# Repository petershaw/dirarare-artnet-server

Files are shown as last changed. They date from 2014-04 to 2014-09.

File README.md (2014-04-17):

dirarare-artnet-server
======================

A ArtNet to DMX node

## Hardware ##
### Schematics ###

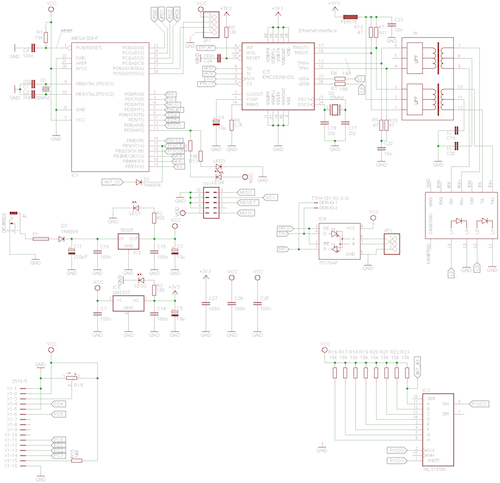
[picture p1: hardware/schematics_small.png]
Schematics


[Full sized schematics](./hardware/schematics.png).

### Partlist ###

| Part | Value |
|:---|---:|
| C1 | 22p |  
| C2 | 22p |
| C3 | 10µ |
| C4 | 100n |
| C5 | 10µ |
| C6 | 10µ |
| C7 | 100n |
| C11 | 220µF |
| C14 | 100n |
| C15 | 100n |
| C16 | 100n |
| C17 | 22p |
| C18 | 22p |
| C19 | 1n |
| C20 | 1n | 
| C22 | 10n | 
| C23 | 10n | 
| C24 | 100n | 
| C25 | 100n | 
| C26 | 100n | 
| C27 | 100n | 
| D1 | 1N4004 | 
| D3 | 1N4004 | 
| DEBUG | TSW-101-02-S-Q |
| F1 | | 
| FERITE | | 
| IC1 | MEGA328-P |
| IC2 | 78S05 |
| IC3 | 74LS165N |  
| IC4 | 75176AP |
| IC5 | ENC28J60-DIL | 
| IC6 | LM2937 |
| J1 | DCJ0202 |
| JP1 | |
| JP2 | |
| LED1 | |
| LED2 | |
| LED3 | |
| LED4 | | 
| Q1 | 20Mhz | 
| Q2 | 25Mhz | 
| R1 | 10k |
| R2 | 820 |
| R3 | 180 |
| R4 | 180 |
| R5 | 10k |
| R6 | 180 |
| R7 | 180 |
| R8 | 2,7k |
| R9 | 47 |
| R10 | 47 |
| R11 | 47 |
| R12 | 47 |
| R13 | 180 |
| R14 | |
| R15 | 180 | 
| R16 | 10k |
| R17 | 10k |
| R18 | 10k |
| R19 | 10k |
| R20 | 10k |
| R21 | 10k |
| R22 | 10k |
| R23 | 10k |
| SV1 | |
| TR | |
| U$1 | |
| X1 | 2516-5 | 

## Software ##

t.b.d. take a look in the code

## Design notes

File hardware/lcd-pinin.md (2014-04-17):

Pin #-LCD	Bezeichnung-LCD	Pin-µC
1	Vss	GND
2	Vcc	5V
3	Vee	GND oder Poti (siehe oben)
4	RS	PD4 am AVR
5	RW	GND
6	E	PD5 am AVR
7	DB0	offen (unbenutzt)
8	DB1	
9	DB2	
10	DB3	
11	DB4	PC0 am AVR
12	DB5	PC1 am AVR
13	DB6	PC2 am AVR
14	DB7	PC3 am AVR

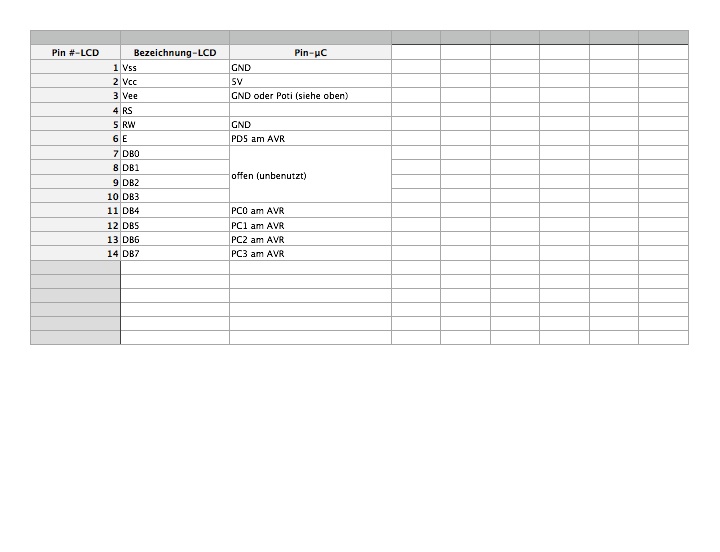
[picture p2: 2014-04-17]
hardware/Pinout-LCD.numbers/preview.jpg

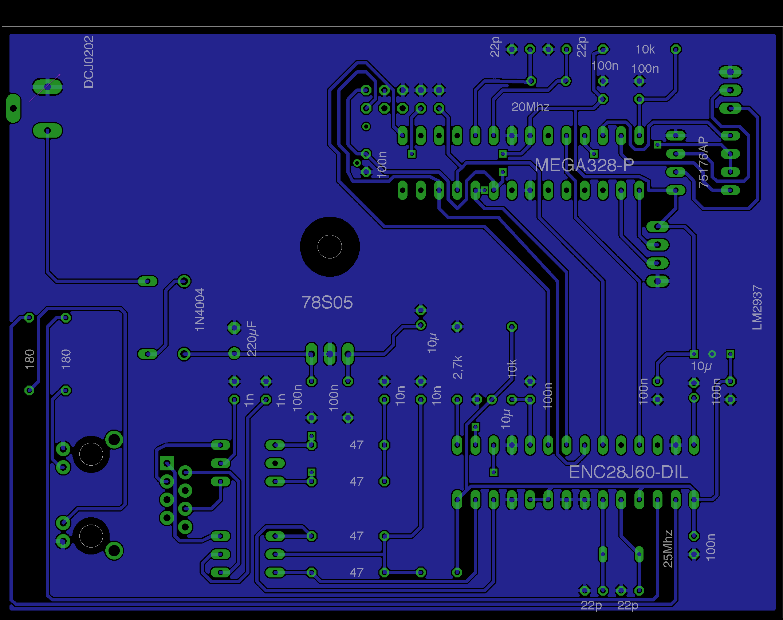
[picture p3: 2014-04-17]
hardware/gnd.png

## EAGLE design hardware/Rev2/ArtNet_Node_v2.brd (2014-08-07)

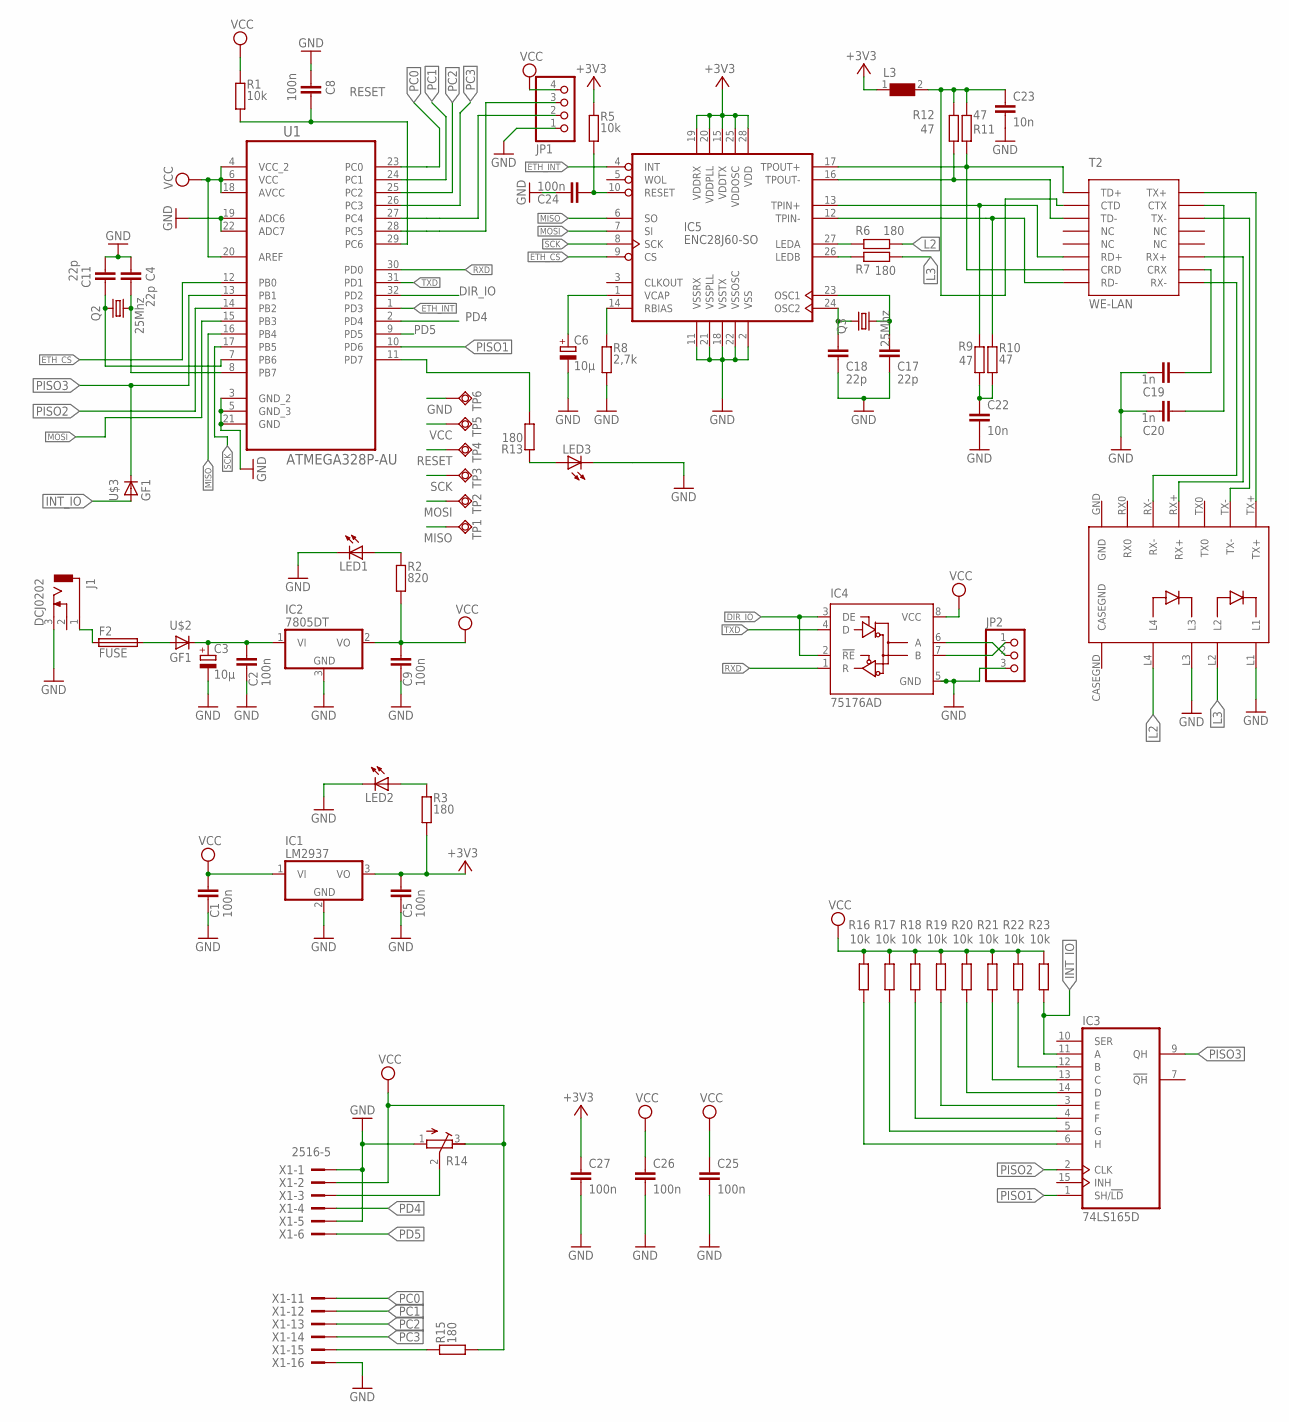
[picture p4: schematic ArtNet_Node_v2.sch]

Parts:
C1, C2, C5, C8, C9, C24, C25, C26, C27: 100n; C1206
C3, C6: 10µ; UD-5X5,8_NICHICON
C4, C11, C17, C18: 22p; C1206
C19, C20: 1n; C1206
C22, C23: 10n; C1206
F2: FUSE; OMNIBLOK
IC1: LM2937; TO263-3
IC2: 7805DT; TO252
IC3: 74LS165D; SO16
IC4: 75176AD; D_R-PDSO-G8
IC5: ENC28J60-SO; SO28W
J1: DCJ0202
JP1: PINHD-1X4; 1X04
JP2: PINHD-1X3; 1X03
L3: WE-SMD_7427930
LED1, LED2: LEDSML1206; SML1206
LED3: LEDSMT1206; 1206
Q2, Q3: 25Mhz; MM20SS
R1, R5, R16, R17, R18, R19, R20, R21, R22, R23: 10k; M1206
R2: 820; M1206
R3, R6, R7, R13, R15: 180; M1206
R8: 2,7k; M1206
R9, R10, R11, R12: 47; M1206
R14: R-TRIMMTS63X; RTRIMTS63X
T2: WE-LAN; WE-LAN_10/100_BASETX_7490100111
TP1, TP2, TP3, TP4, TP5, TP6: TPSQTP20SQ; TP20SQ
U1: ATMEGA328P-AU; QFP80P900X900X120-32N
U$1: 1XRJ45_MM_JACK
U$2, U$3: GF1; SMA-DO214AC
X1: 2516-5; PAK100/2500-5-16

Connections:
+3V3: C5.2, C27.1, IC1.3 (VO), IC5.15 (VDDTX), IC5.19 (VDDRX), IC5.20 (VDDPLL), IC5.25 (VDDOSC), IC5.28 (VDD), L3.1, R3.1, R5.2
DIR_IO: IC4.2 (!RE), IC4.3 (DE), U1.32 (PD2)
ETH_CS: IC5.9 (CS), U1.12 (PB0)
ETH_INT: IC5.4 (INT), U1.1 (PD3)
INT_IO: IC3.11 (A), R23.2, U$3.A
L2: R6.1, U$1.L4
L3: R7.1, U$1.L2
MISO: IC5.6 (SO), TP1.TP, U1.16 (PB4)
MOSI: IC5.7 (SI), TP2.TP, U1.15 (PB3)
unnamed: T2.16 (TX+), U$1.TX+
unnamed: C19.1, T2.10 (CRX)
unnamed: T2.14 (TX-), U$1.TX-
unnamed: C20.1, T2.15 (CTX)
unnamed: F2.P$2 (2), U$2.A
unnamed: T2.11 (RX+), U$1.RX+
unnamed: T2.9 (RX-), U$1.RX-
unnamed: IC4.7 (B), JP2.1
unnamed: F2.P$1 (1), J1.1
unnamed: IC5.27 (LEDA), R6.2
unnamed: JP1.2, U1.27 (PC4)
unnamed: IC4.6 (A), JP2.2
unnamed: IC5.26 (LEDB), R7.2
unnamed: C2.2, C3.+, IC2.1 (VI), U$2.K (C)
unnamed: LED2.A, R3.2
unnamed: C18.2, IC5.24 (OSC2), Q3.4 (2)
unnamed: C17.2, IC5.23 (OSC1), Q3.1
unnamed: IC5.12 (TPIN-), R10.2, T2.8 (RD-)
unnamed: IC5.13 (TPIN+), R9.2, T2.6 (RD+)
unnamed: IC5.16 (TPOUT-), R12.2, T2.3 (TD-)
unnamed: IC5.17 (TPOUT+), R11.2, T2.1 (TD+), T2.7 (CRD)
unnamed: IC5.14 (RBIAS), R8.2
unnamed: C6.+, IC5.1 (VCAP)
unnamed: JP1.3, U1.28 (PC5)
unnamed: C22.1, R9.1, R10.1
unnamed: C24.2, IC5.10 (RESET), R5.1
unnamed: LED1.A, R2.2
unnamed: R13.1, U1.11 (PD7)
unnamed: R14.2 (S), X1.3
unnamed: LED3.A, R13.2
unnamed: R15.2, X1.15
unnamed: IC3.12 (B), R22.2
unnamed: IC3.13 (C), R21.2
unnamed: IC3.14 (D), R20.2
unnamed: IC3.3 (E), R19.2
unnamed: IC3.4 (F), R18.2
unnamed: IC3.5 (G), R17.2
unnamed: IC3.6 (H), R16.2
unnamed: C4.1, Q2.1, U1.8 (PB7)
unnamed: C11.1, Q2.4 (2), U1.7 (PB6)
unnamed: C23.1, L3.2, R11.1, R12.1, T2.2 (CTD)
PC0: U1.23 (PC0), X1.11
PC1: U1.24 (PC1), X1.12
PC2: U1.25 (PC2), X1.13
PC3: U1.26 (PC3), X1.14
PD4: U1.2 (PD4), X1.4
PD5: U1.9 (PD5), X1.6
PISO1: IC3.1 (SH/!LD), U1.10 (PD6)
PISO2: IC3.2 (CLK), U1.14 (PB2)
PISO3: IC3.9 (QH), U1.13 (PB1), U$3.K (C)
RESET: C8.1, R1.1, TP4.TP, U1.29 (PC6)
RXD: IC4.1 (R), U1.30 (PD0)
TXD: IC4.4 (D), U1.31 (PD1)
VCC: C1.2, C9.2, C25.2, C26.1, IC1.1 (VI), IC2.2 (VO), IC3.16 (VCC), IC4.8 (VCC), JP1.4, R1.2, R2.1, R14.3 (A), R15.1, R16.1, R17.1, R18.1, R19.1, R20.1, R21.1, R22.1, R23.1, TP5.TP, U1.4 (VCC_2), U1.6 (VCC), U1.18 (AVCC), U1.20 (AREF), X1.2

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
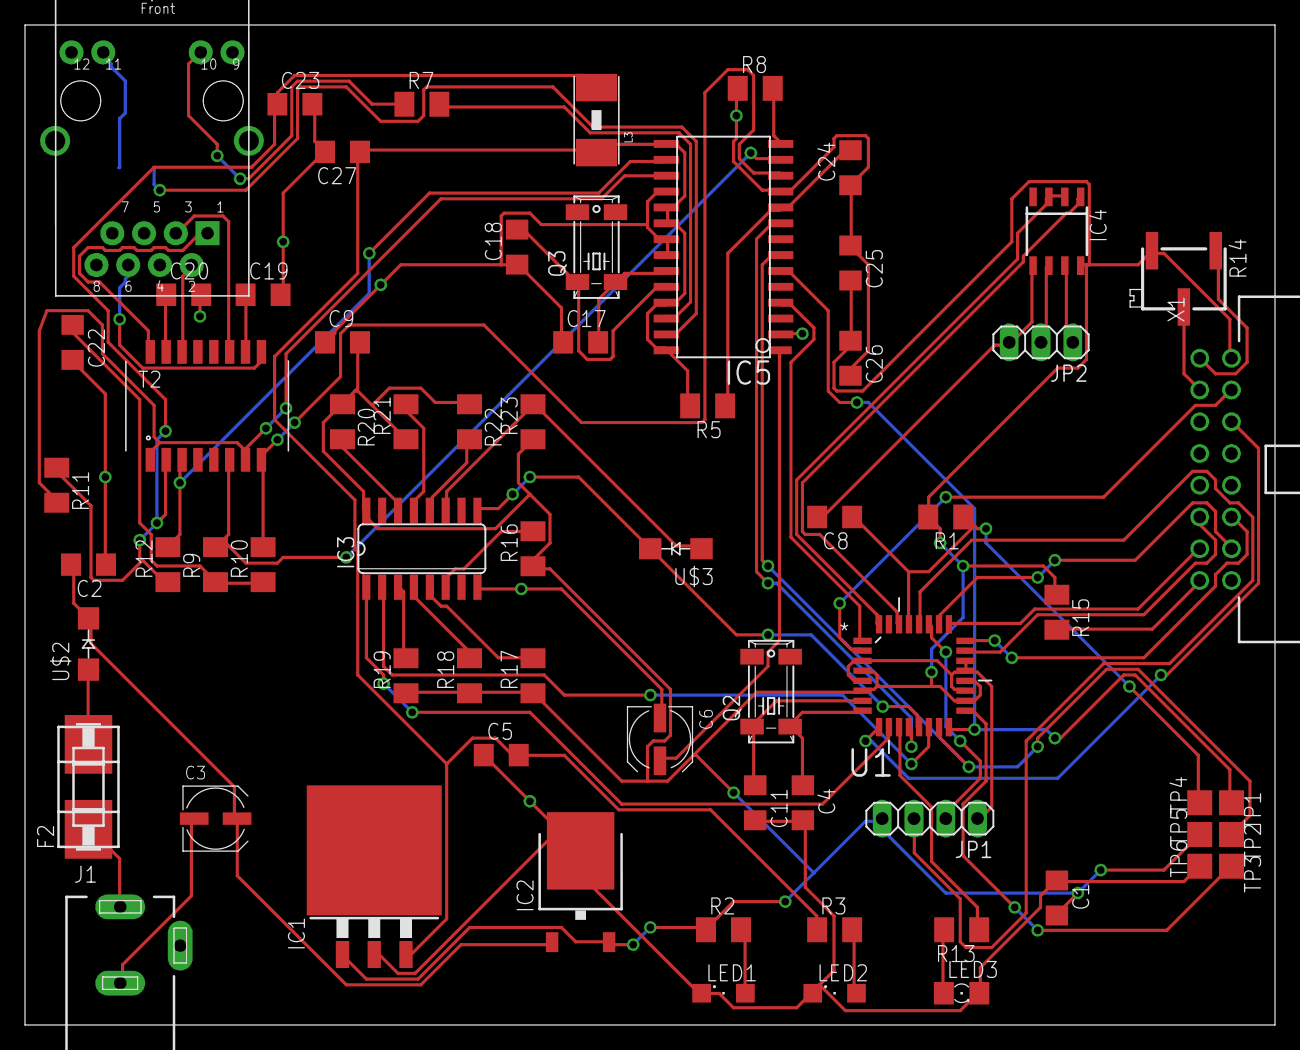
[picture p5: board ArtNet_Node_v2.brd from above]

Board: 2 copper layers, 100.0 x 80.0 mm, 68 parts (1 on the bottom side), 64 nets.

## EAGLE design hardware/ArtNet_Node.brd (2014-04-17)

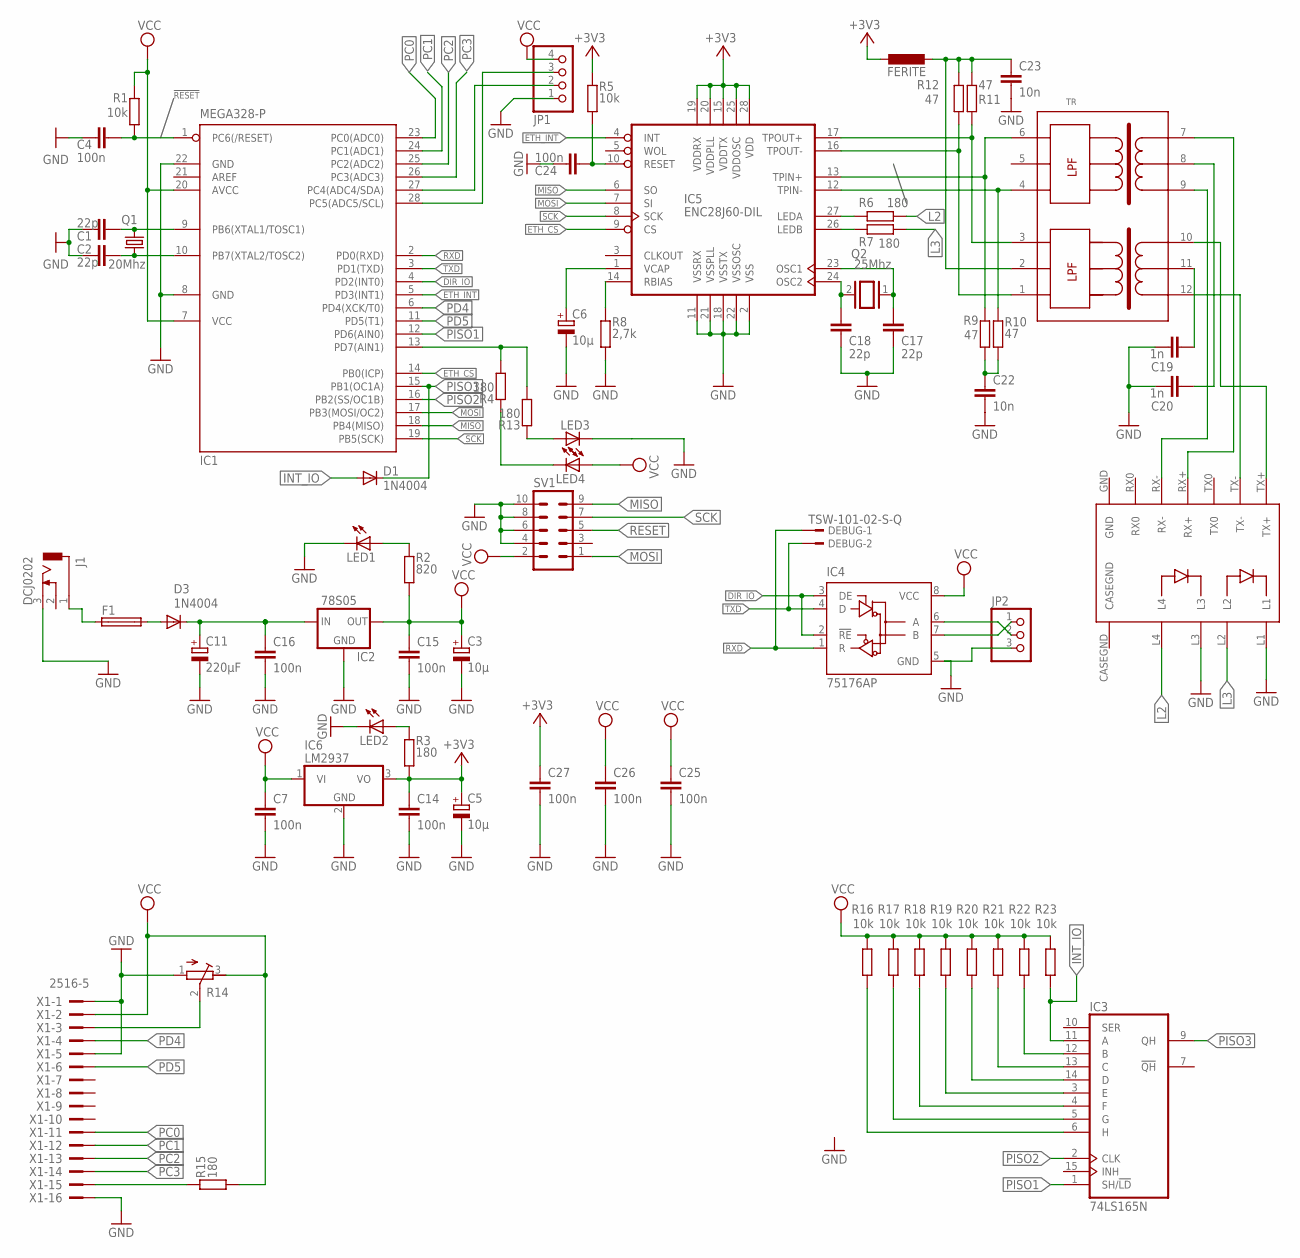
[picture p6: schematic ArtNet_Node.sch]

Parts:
C1, C2, C17, C18: 22p; C025-024X044
C3, C5, C6: 10µ; E2-5
C4, C7, C14, C24: 100n; C025-024X044
C11: 220µF; E3,5-8
C15, C16: 100n; C050-024X044
C19, C20: 1n; C025-024X044
C22, C23: 10n; C025-025X050
C25, C26, C27: 100n; C025-025X050
D1, D3: 1N4004; DO41-10
DEBUG: TSW-101-02-S-Q
F1: PICOFUSE
FERITE: L-EU0204/5; 0204/5
IC1: MEGA328-P; DIL28-3
IC2: 78S05; 78XXL
IC3: 74LS165N; DIL16
IC4: 75176AP; DIL08
IC5: ENC28J60-DIL; DIL28-3
IC6: LM2937; TO263-3
J1: DCJ0202
JP1: PINHD-1X4; 1X04
JP2: PINHD-1X3; 1X03
LED1, LED2, LED3, LED4: LED5MM
Q1: 20Mhz; HC49U-V
Q2: 25Mhz; QS
R1, R5, R16, R17, R18, R19, R20, R21, R22, R23: 10k; 0207/10
R2: 820; 0207/10
R3, R4, R6, R7, R13, R15: 180; 0207/10
R8: 2,7k; 0207/10
R9, R10, R11, R12: 47; 0207/10
R14: R-TRIMM74X; RTRIM74X
SV1: ML10L
TR: 20F001; DIL16/12
U$1: 1XRJ45_MM_JACK
X1: 2516-5; PAK100/2500-5-16

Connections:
!RESET: C4.2, IC1.1 (PC6(/RESET)), R1.1
+3V3: C5.+, C14.1, C27.1, FERITE.1, IC5.15 (VDDTX), IC5.19 (VDDRX), IC5.20 (VDDPLL), IC5.25 (VDDOSC), IC5.28 (VDD), IC6.3 (VO), R3.1, R5.2
DIR_IO: IC1.4 (PD2(INT0)), IC4.2 (!RE), IC4.3 (DE)
ETH_CS: IC1.14 (PB0(ICP)), IC5.9 (CS)
ETH_INT: IC1.5 (PD3(INT1)), IC5.4 (INT)
GND: C1.1, C2.1, C3.-, C4.1, C5.-, C6.-, C7.2, C11.-, C14.2, C15.2, C16.2, C17.1, C18.1, C19.2, C20.2, C22.2, C23.2, C24.1, C25.1, C26.2, C27.2, IC1.8 (GND), IC1.22 (GND), IC2.GND, IC3.8 (GND), IC4.5 (GND), IC5.2 (VSS), IC5.11 (VSSRX), IC5.18 (VSSTX), IC5.21 (VSSPLL), IC5.22 (VSSOSC), IC6.2 (GND), J1.3, JP1.1, JP2.3, LED1.K (C), LED2.K (C), LED3.K (C), R8.1, R14.1 (E), SV1.4, SV1.6, SV1.8, SV1.10, U$1.L1, U$1.L3, X1.1, X1.5, X1.16
L2: R6.1, U$1.L4
L3: R7.1, U$1.L2
MISO: IC1.18 (PB4(MISO)), IC5.6 (SO), SV1.9
MOSI: IC1.17 (PB3(MOSI/OC2)), IC5.7 (SI), SV1.1
unnamed: C2.2, IC1.10 (PB7(XTAL2/TOSC2)), Q1.1
unnamed: C1.2, IC1.9 (PB6(XTAL1/TOSC1)), Q1.2
unnamed: TR.9, U$1.RX-
unnamed: D3.A, F1.2
unnamed: TR.12, U$1.TX-
unnamed: TR.10, U$1.TX+
unnamed: IC4.7 (B), JP2.1
unnamed: F1.1, J1.1
unnamed: IC5.27 (LEDA), R6.2
unnamed: IC1.27 (PC4(ADC4/SDA)), JP1.2
unnamed: IC4.6 (A), JP2.2
unnamed: IC5.26 (LEDB), R7.2
unnamed: TR.7, U$1.RX+
unnamed: C20.1, TR.8
unnamed: C19.1, TR.11
unnamed: C18.2, IC5.24 (OSC2), Q2.2
unnamed: C17.2, IC5.23 (OSC1), Q2.1
unnamed: IC5.12 (TPIN-), R10.2, TR.4
unnamed: IC5.13 (TPIN+), R9.2, TR.6
unnamed: IC5.16 (TPOUT-), R12.2, TR.1
unnamed: IC5.17 (TPOUT+), R11.2, TR.3
unnamed: IC5.14 (RBIAS), R8.2
unnamed: C6.+, IC5.1 (VCAP)
unnamed: IC1.28 (PC5(ADC5/SCL)), JP1.3
unnamed: C22.1, R9.1, R10.1
unnamed: C24.2, IC5.10 (RESET), R5.1
unnamed: LED1.A, R2.2
unnamed: LED2.A, R3.2
unnamed: IC1.13 (PD7(AIN1)), R4.1, R13.1
unnamed: R14.2 (S), X1.3
unnamed: LED3.A, R13.2
unnamed: LED4.K (C), R4.2
unnamed: D1.A, IC3.11 (A), R23.2
unnamed: R15.2, X1.15
unnamed: IC3.12 (B), R22.2
unnamed: IC3.13 (C), R21.2
unnamed: IC3.14 (D), R20.2
unnamed: IC3.3 (E), R19.2
unnamed: IC3.4 (F), R18.2
unnamed: IC3.5 (G), R17.2
unnamed: IC3.6 (H), R16.2
unnamed: C23.1, FERITE.2, R11.1, R12.1, TR.2
unnamed: C11.+, C16.1, D3.C, IC2.IN
PC0: IC1.23 (PC0(ADC0)), X1.11
PC1: IC1.24 (PC1(ADC1)), X1.12
PC2: IC1.25 (PC2(ADC2)), X1.13
PC3: IC1.26 (PC3(ADC3)), X1.14
PD4: IC1.6 (PD4(XCK/T0)), X1.4
PD5: IC1.11 (PD5(T1)), X1.6
PISO1: IC1.12 (PD6(AIN0)), IC3.1 (SH/!LD)
PISO2: IC1.16 (PB2(SS/OC1B)), IC3.2 (CLK)
PISO3: D1.C, IC1.15 (PB1(OC1A)), IC3.9 (QH)
RESET: SV1.5
RXD: DEBUG.1, IC1.2 (PD0(RXD)), IC4.1 (R)
SCK: IC1.19 (PB5(SCK)), IC5.8 (SCK), SV1.7
TXD: DEBUG.2, IC1.3 (PD1(TXD)), IC4.4 (D)
VCC: C3.+, C7.1, C15.1, C25.2, C26.1, IC1.7 (VCC), IC1.20 (AVCC), IC2.OUT, IC3.16 (VCC), IC4.8 (VCC), IC6.1 (VI), JP1.4, R1.2, R2.1, R14.3 (A), R15.1, R16.1, R17.1, R18.1, R19.1, R20.1, R21.1, R22.1, R23.1, SV1.2, X1.2

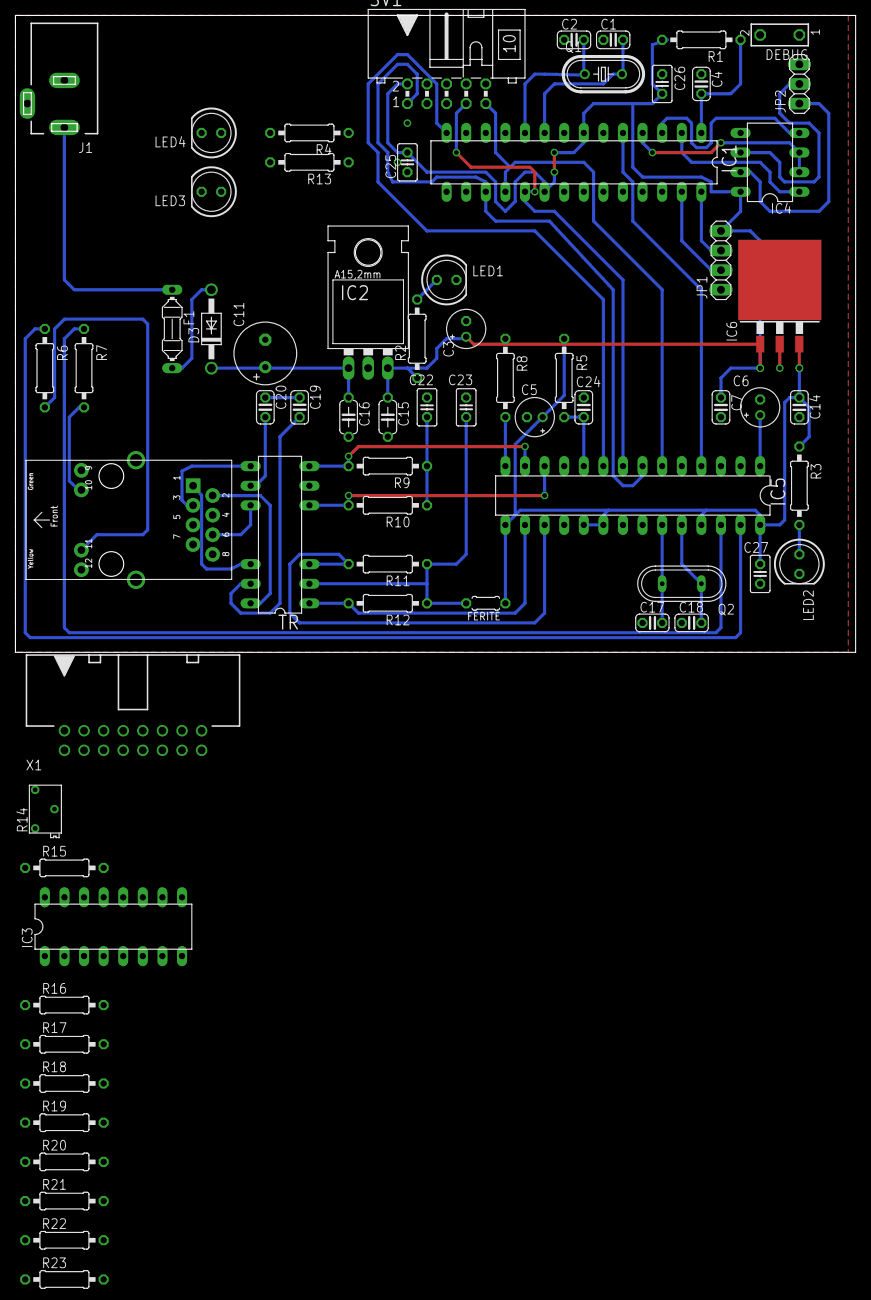
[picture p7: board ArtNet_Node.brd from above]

Board: 2 copper layers, 108.9 x 82.5 mm, 67 parts (0 on the bottom side), 66 nets.

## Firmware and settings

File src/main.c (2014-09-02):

//
//  main.c
//  Dirarare-ArtNet-Server
//  Revision 2.0
//	

#include <stdlib.h>
#include <stdbool.h>

#include <util/delay.h>
#include <avr/io.h>
#include <avr/interrupt.h>
#include <avr/pgmspace.h>

#include "config.h"
#include "global.h"
#include "output/usart.h"
#include "../src-lib/lcd/lcd.h"
#include "drv/eeprom.h"
#include "input/inputs.h"
#include "functions/abstractFunction.h"
#include "functions/ip.h"
#include "functions/save.h"
#include "ui/menu.h"
#include "ui/menuController.h"
#include "net/stack.h"
#include "net/udp_cmd.h"
#include "artnet/artnet.h"
#include "ctrl/timer.h"

#define WAIT 200
	
static char lcd_buf[16];

//@todo: ETH_CS auf Port PD7 legen!



int main(void) {	

	
	isActive = 0;
    // BOOT DISPLAY
    // -----------------------------------------
 	lcd_init(LCD_DISP_ON_CURSOR);
	lcd_clrscr();
	lcd_home();
	lcd_puts_p(PSTR("Dirarare.\nbooting..."));
	
	// READ EEPROM
    // -----------------------------------------
	eeprom_open();
	int r = eeprom_read(&ip, 	15 );
	r += 	eeprom_read(&net, 	15 );
	r += 	eeprom_read(&gw, 	15 );
	eeprom_close();
	
	// check if first position is a number // otherwise reset!
	if( ip[0]  < 48 ||  ip[0] > 57){   ip[0] = '\0'; }
	if(net[0]  < 48 || net[0] > 57){  net[0] = '\0'; }
	if( gw[0]  < 48 ||  gw[0] > 57){   gw[0] = '\0'; }
		

	// CONFIG INPUTS & MENU
    // -----------------------------------------
	fn_init();
	ui_menu_init();
	ui_menucontroller_init();
	
	ui_menu_add("IP",		fn_firnament_ip, 	&ip );
 	ui_menu_add("Netmask",	fn_firnament_ip, 	&net);
 	ui_menu_add("Gateway",	fn_firnament_ip, 	&gw );
	ui_menu_add("Save",		fn_firnament_save, 	NULL);
	
	//------------------------------------------------------------------
	//END CONFIG INPUTS & MENU


    // STARTUP APPLICATION
    // -----------------------------------------
 	/*usart_init(BAUDRATE);
 	stack_init();
 	udp_cmd_init();
 	artnet_init();*/
	timer_init();
	
	//Ethernetcard Interrupt enable
	/*ETH_INT_ENABLE;*/
	
	//------------------------------------------------------------------
	//END STARTUP APPLICATION
	initialize_inputs(); //geht nicht
    // STARTUP MESSAGES
    //------------------------------------------------------------------
	/*lcd_clrscr();
	//lcd_gotoxy(0,0);
	lcd_puts_p(PSTR("Dirarare Rev.2\n"));	// welcome message
	lcd_puts(BUILD_DATE_SHORT);
 
	//_delay_ms(WAIT);
	
	//lcd_clrscr();
	//lcd_gotoxy(0,0);
	lcd_puts_p(PSTR("IP:\n"));
    lcd_puts(ip);
	_delay_ms(WAIT);	

	//lcd_clrscr();	
	//lcd_gotoxy(0,0);
	lcd_puts_p(PSTR("Netmask:\n"));
    lcd_puts(net);
	_delay_ms(WAIT);	
	
	//lcd_clrscr();	
	//lcd_gotoxy(0,0);
	lcd_puts_p(PSTR("Gateway:\n"));
    lcd_puts(gw);
	_delay_ms(WAIT);	

    
	//lcd_clrscr();
	//lcd_gotoxy(0,0);
	lcd_puts(ip);
	lcd_puts_p(PSTR("\n"));*/
	
	//ui_menucontroller_defaultoff(0);
	
	//------------------------------------------------------------------
	//END STARTUP MESSAGES
	
	//initialize_inputs(); //finktioniert
    // ENABLE GLOBAL INTERRUPTS
    //------------------------------------------------------------------
    //sei(); 
	// END GLOBLA INTERRUPTS


    // MAINLOOP
	//------------------------------------------------------------------
	while(1){

		if(next_action != PRESSED_ENTER){
			ui_menucontroller_show(); 			
			next_action = 0;
			
 			_delay_ms(300);
 			ui_menucontroller_hide();
 		}	
 		
 		
		/*eth_get_data();
		artnet_main(); */
	}
	
	//------------------------------------------------------------------
	//END MAINLOOP
	
}

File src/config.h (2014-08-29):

#ifndef _CONFIG_H_
	#define _CONFIG_H_	

	// *** ================================================
	// *** NETWORK
	// *** ================================================
	//Umrechnung von IP zu unsigned long
	#define IP(a,b,c,d) ((unsigned long)(d)<<24)+((unsigned long)(c)<<16)+((unsigned long)(b)<<8)+a

		
	//MAC Adresse des ART NET NODES	
	#define MYMAC1	0x00
	#define MYMAC2	0x22
	#define MYMAC3	0xF9
	#define MYMAC4	0x01	
	#define MYMAC5	0x1D
	#define MYMAC6	0xA6


	// *** ================================================
	// *** DMX
	// *** ================================================
	//Baudrate der seriellen Schnittstelle
	#define BAUDRATE 57600


	// *** ================================================
	// *** BUTTONS & ENCODERS
	// *** ================================================
	#define ENCODER_REGISTER	DDRB
	#define ENCODER_PORT		PORTB
	#define ENCODER_PIN_PUSH	PB0
	#define ENCODER_PIN_TURN0	PB1		
	#define ENCODER_PIN_TURN1	PB2
	
	
	
	// *** ================================================
	// *** EEPROM
	// *** ================================================
	#define EEPROM_STARTADDR				0x8		// 8
	#define EEPROM_MAX_BYTES				0x3ff	//1023
    
#endif //_CONFIG_H

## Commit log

2014-04-17 REV.1
    Initial commit.
    _works on the test board
    [ArtNet_Node.brd, ArtNet_Node.sch]
2014-04-17 Add schematics
2014-04-17 Add full size schematics
2014-08-07 Rev2 First Commit
    [ArtNet_Node_v2.brd, ArtNet_Node_v2.sch]
2014-08-28 set Fuses while upload
    The AVR use a 16MHZ, the fuse bit's are nessassary to set.
2014-08-28 rewrite menucontroller button handling
2014-08-29 Remove status LED
2014-08-29 Fixes compiler warning for main.c
    [main.c]
2014-08-29 Rotary Encoder Code
2014-08-30 Rotary encoder via timer
2014-09-02 Encoder Timer Debug Session
2014-09-02 Encoder Menu Code

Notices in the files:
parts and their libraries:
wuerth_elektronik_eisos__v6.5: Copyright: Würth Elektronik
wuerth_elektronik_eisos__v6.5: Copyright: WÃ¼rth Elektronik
